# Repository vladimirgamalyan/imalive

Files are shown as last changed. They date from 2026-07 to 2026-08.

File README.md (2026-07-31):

# imalive



An **"I'm alive" heartbeat device** on an ESP32-C3 SuperMini. It helps you tell
whether **mains power is present** at a remote location (home, cottage, office) —
without any voltage sensor.

The trick is inversion: the device is powered by the very mains supply it watches,
so *the device being online is the signal*. It never claims "power is back" (it
cannot tell power from internet or a hang) — it only ever reports that **it is
alive**, and you infer the rest.

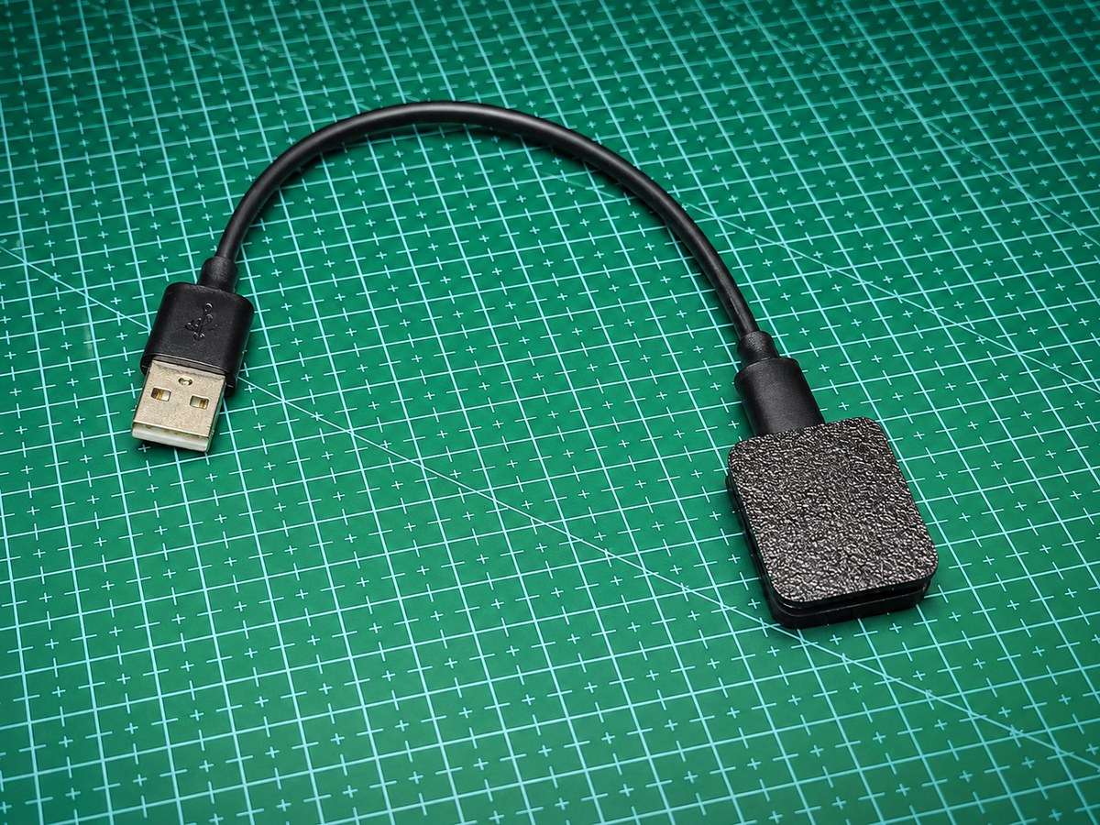
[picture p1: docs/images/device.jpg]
Assembled device


## Highlights

- **No sensors, no cloud, no server** — a $2 board and a Telegram bot. The
  device being online *is* the measurement.
- **One message, zero spam** — the device keeps **editing a single Telegram
  message** instead of posting new ones. Edits are silent; when power drops, the
  message freezes at the last `Last seen`, which is exactly the answer you need.
- **OTA updates over Telegram** — send a `firmware.bin` to the bot and the
  device reflashes itself from anywhere in the world.
- **Round-clock heartbeats** — updates are phase-locked to wall-clock times
  (14:00, 14:30, …), so the timestamps are predictable at a glance.

## How it works

1. On a genuine power-on it connects to WiFi, syncs the clock over NTP, and sends
   a Telegram message with a `Last seen` timestamp (prefixed by `DEVICE_NAME`, if
   set). It ships **muted** (silent); send `/unmute` once so that real power-ons
   notify.
2. While powered, every `HEARTBEAT_MIN` minutes it **edits that same message** to
   refresh a `Last seen` line. Editing raises **no** notification, so the chat is
   not spammed.
3. When power drops, the device dies and the message **freezes** at its last
   `Last seen` — telling you until when power (and the device) was definitely there.

The `message_id` is kept in flash (NVS), so a spontaneous reboot (watchdog / OTA)
resumes the **same** message silently — no false "power is back" ping. Once
`/unmute`d, a real power-on notifies; you can `/mute` again for planned downtime
(see [Commands](#commands)). See [`CONCEPT.md`](CONCEPT.md) and the
[decision records](docs/adr/) for the full rationale.

### Message example

```
The Fine Place Resort
On since: 14:32 24 Jul
Last seen: 16:02 24 Jul (updated every 30m)
```

The `On since` line appears only while notifications are armed (`/unmute`); a muted
device shows just `Last seen`.

## Hardware

- **ESP32-C3 SuperMini** (2.4 GHz WiFi; the C3 has no 5 GHz).
- Powered from USB / a 5 V adapter plugged into the socket you want to monitor.
- Onboard blue LED (GPIO8) is used as a WiFi status indicator:
  - **blinking** — connecting to WiFi;
  - **solid** — connected.
- A 3D-printable enclosure lives in [`case/`](case/) — print `top.stl` and
  `bottom.stl`.

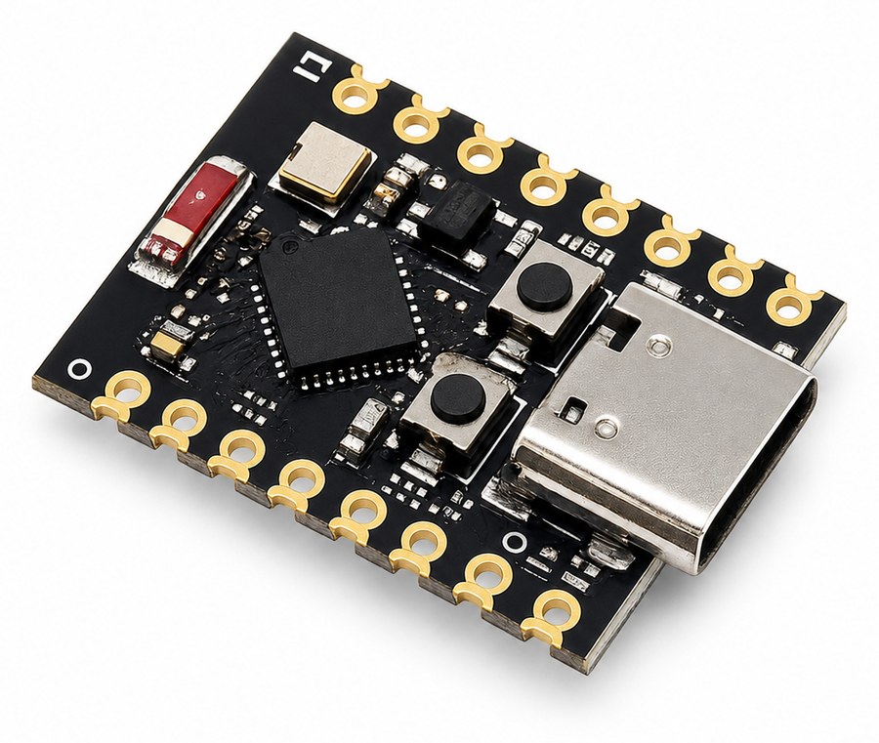
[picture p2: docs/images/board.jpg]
ESP32-C3 SuperMini


## Getting started

### 1. Install PlatformIO

Install [PlatformIO Core](https://docs.platformio.org/en/latest/core/installation/)
(`pio`) or the PlatformIO IDE extension for VS Code.

### 2. Configure

Copy the template and fill in your values:

```sh
cp include/config.example.h include/config.h
```

`include/config.h` is git-ignored and must never be committed.

| Field | Meaning |
| --- | --- |
| `WIFI_SSID` / `WIFI_PASSWORD` | Your 2.4 GHz WiFi credentials |
| `TG_BOT_TOKEN` | Bot token from [@BotFather](https://t.me/BotFather) |
| `TG_CHAT_ID` | **Recipient** chat id — a personal chat or a channel |
| `TG_ADMIN_IDS` | User IDs allowed to command the bot, e.g. `{ 111, 222 }` |
| `HEARTBEAT_MIN` | Heartbeat interval in minutes (default `30`) |
| `DEVICE_NAME` | Optional label shown in the message, e.g. `"Cottage"` |
| `TZ_STRING` | POSIX timezone, DST-aware (default `"ICT-7"`, Asia/Bangkok) |

### 3. Telegram setup

1. Create a bot with [@BotFather](https://t.me/BotFather) and copy its token.
2. **Send your bot a message first** (e.g. `/start`). A bot cannot start a
   conversation, so without this it can never message you.
3. Find your chat id: open
   `https://api.telegram.org/bot<TOKEN>/getUpdates` and read
   `result[].message.chat.id`.
   - ⚠️ This is the **recipient's** id, *not* the bot's own id (the number before
     `:` in the token). Sending to the bot's own id fails.
   - For a **channel**: add the bot as an **administrator** with post permission
     and use a `chat_id` like `-100...` (or `@channelusername`).

Multiple devices can share one chat/channel — each edits only its own message.
Give them distinct `DEVICE_NAME`s to tell them apart.

### 4. Build and flash

```sh
pio run                 # build
pio run -t upload       # build + flash over USB
pio device monitor      # optional serial console (115200 baud)
```

Watch the blue LED: once it stays solid, WiFi is up and the first message should
arrive in your chat within a few seconds.

USB flashing is only needed once — after that the device updates over the air
(see [Firmware update](#firmware-update-ota)).

## Commands

Direct-message the bot (only the user IDs in `TG_ADMIN_IDS` are answered; anyone
else is ignored). The bot publishes these to its Telegram command menu on boot, so
you can pick them from the `/` menu instead of typing:

- `/status` — the device replies with its configuration (name, timezone, chat,
  WiFi SSID, admin IDs) and live state: firmware version, uptime, WiFi signal
  (RSSI), IP address, when it came online, the current time, and whether startup
  pings are muted.
- `/mute` — silence the notification on the next power-on. Send this **before** a
  planned power-off (reflashing, moving sockets); wait for the reply, then power
  down. The device resumes its message silently on the next start.
- `/unmute` — arm startup notifications (the device ships muted), so the next real
  power-on pings again.

On every boot the device also sends a short **silent** notice to each admin's
private chat — so soft reboots (watchdog, panic, OTA), which the main chat
deliberately hides, are still visible to you. It carries the reset reason, the
firmware version, how long the previous session lasted, and the lifetime count
of watchdog reboots (shown once it is non-zero), which tells a one-off network
stall apart from a systematic hang.

## Firmware update (OTA)

There is no update command: build with `pio run`, then send
`.pio/build/esp32-c3-supermini/firmware.bin` to the bot **as a document**. Any
document from an admin whose name ends in `.bin` is treated as firmware — no
command, no caption.

The device flashes it into the spare OTA slot, reboots, silently resumes its
message, and replies with the new version. If the new firmware fails to start
three times in a row, the device rolls back to the previous image and reports
the failure.

## Timezone

`TZ_STRING` is a POSIX TZ string, so daylight-saving transitions are handled
automatically. Examples:

- `ICT-7` — Asia/Bangkok (UTC+7, no DST) — the shipped default.
- `EET-2EEST,M3.5.0/3,M10.5.0/4` — Eastern European (UTC+2 / +3).
- `CET-1CEST,M3.5.0,M10.5.0/3` — Central European (UTC+1 / +2).
- `MSK-3` — Moscow (UTC+3, no DST).

## Limitations

By design the device cannot distinguish **no power** from **no internet** or a
**hang** — all three simply stop the heartbeat. It also does not send an
in-the-moment "power lost" message (no supercapacitor), and a full but very brief
outage (a few seconds) still counts as a real power-on. These are deliberate
tradeoffs; see [`CONCEPT.md` §7](CONCEPT.md) and the [ADRs](docs/adr/).

## Repository layout

```
platformio.ini            PlatformIO project (ESP32-C3 SuperMini, Arduino)
include/config.example.h  config template (copy to config.h)
src/main.cpp              firmware
case/                     3D-printable enclosure (STL)
CONCEPT.md                design concept and tradeoffs
docs/adr/                 architecture decision records
```

## License

[MIT](LICENSE) © Vladimir Gamalyan

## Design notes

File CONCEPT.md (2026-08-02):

# imalive — an "I'm alive" heartbeat device on ESP32-C3

Status: **implemented**. This is the origin concept; where the firmware refined it,
the `docs/adr/` records win — notably ADR-0008 changed the persistence and
notification model described below.

Purpose: help an operator tell whether **mains power is present** at a remote
location — but the device only ever asserts its own **liveness** ("I'm alive").
Inferring "power is present" from that liveness is left to the human. This keeps
the device honest: it never claims something it cannot actually know.

## 1. Idea

An ESP32-C3 device stays permanently plugged into a wall socket at the monitored
location (home / cottage / office). It keeps a connection to Telegram and, as long
as it is running, periodically reports **"I'm alive"** to a chat.

**Core idea (inversion):** the device is powered by the same mains supply it helps
monitor, so its own liveness carries the signal. If the device is alive and online,
the operator can infer that power is present. We do not need a separate voltage
sensor — the device's own power supply *is* what keeps it alive.

The device deliberately reports **only liveness**, never "power is back". It cannot
distinguish "no power" from "no internet" or "device hung" (see §7), so claiming
anything about power directly would be misleading. The project name — *imalive* /
"I'm alive" — matches exactly what the device asserts.

## 2. What the observer sees

- **Device comes online** → it posts a `Last seen` line (prefixed by `DEVICE_NAME`
  if set). A genuine mains power-on posts a **new** message and is the only
  sound-notification — and only when notifications are *armed* (the device ships
  **muted**, ADR-0008). A spontaneous reboot (watchdog / OTA) or a muted restart
  **resumes the existing message** silently.
- **While the device is alive** → every N minutes it **edits that same message**
  (via `editMessageText`), updating the "last seen" line. Editing a Telegram
  message does **not** raise a new notification — so the chat is not spammed.
- **Device stops** (power lost, internet lost, or a hang) → it goes silent and the
  message "freezes" at its last "last seen" value.

So the operator can always look at the last message and reason:
"the device was definitely alive within the last N minutes" (fresh "last seen") or
"the device went silent around HH:MM" (stale "last seen") — and from that infer
whether power is present.

### Message example

Right after coming online (`DEVICE_NAME` is the first line, omitted if unset; the
`On since` line appears only when armed / un-muted; a muted device shows just
`Last seen`):

```
Cottage
On since: 14:32 24 Jul
Last seen: 14:32 24 Jul (updated every 30m)
```

After a few heartbeats (same message, edited in place):

```
Cottage
On since: 14:32 24 Jul
Last seen: 16:02 24 Jul (updated every 30m)
```

If the device goes silent after 16:02, the message stays at "Last seen: 16:02" —
the operator reads that as "the device (and therefore power) was present at least
until ~16:02".

> Note: the runtime wording and language of the Telegram messages is a product
> choice, not fixed here. Russian is the natural default since the operator reads
> them; the examples above are shown in English only to keep this doc consistent.

## 3. Lifecycle (state machine)

```
[POWER ON]
   │
   ▼
Connect to WiFi ──(failed)──► retry with backoff (router may still be booting)
   │ (success)
   ▼
Time sync over NTP
   │
   ▼
Load message_id / online_since / mute from NVS
   │
   ▼
if (reset reason == POWER-ON) and (not muted):
      sendMessage("I'm alive …", notify)    # new session; online_since = now
else:                                        # watchdog / OTA / muted power-off
      editMessageText(message_id, …)         # resume the existing message, silent
   │
   ▼
┌─► wait N minutes
│      │
│      ▼
│  editMessageText(message_id, "… Last seen: HH:MM")
│      │  (edit error — §7 fallback: a fresh silent message)
└──────┘
   ⋮
[DEVICE STOPS] → device goes silent, sends nothing
```

The boot is classified via `esp_reset_reason()` (ADR-0008): only a genuine
`ESP_RST_POWERON` while un-muted starts a fresh, **notifying** session and resets
"online since". Every other cause — watchdog, OTA, software restart — or a muted
power-off **resumes** the persisted message in place, keeping "online since". The
`message_id`, "online since" and mute flag survive in NVS; this is what fixes the
spontaneous-reboot false positive once noted in §7.

## 4. Inferring power loss (from liveness)

The device never sends a "power lost" message — when power drops at that location
the router is usually unpowered too, so the device would not physically have time
to send anything (a supercapacitor / power reserve was deliberately **not** added).
Equally, the device never asserts "power is present"; it only asserts liveness.

Power loss is **inferred by the human** from the "Last seen" line no longer
updating. The **resolution** of that inference equals the heartbeat interval (N
minutes): with N = 30 min the device went silent somewhere in the window
[last "last seen"; last "last seen" + 30 min].

The last heartbeat time is **not** persisted, so the device does not compute a
silent-duration on the next start — only `message_id`, "online since" and the mute
flag are kept (ADR-0008). On a real, un-muted power-on it posts a fresh message and
the previous one freezes, so the human still estimates the gap from that frozen
message in the chat history.

## 5. Timings

- **Online (liveness) detection latency**: practically instant — ESP boot time +
  WiFi connect + NTP ≈ 10–30 s.
- **Heartbeat interval (N)**: default **30 minutes** (candidates: 30 / 60),
  exposed in config. Tradeoff: smaller N → fresher "last seen" and a tighter
  silence estimate, but more Telegram API calls.

## 6. Technical stack and hardware

- **Board**: **ESP32-C3 SuperMini**, 2.4 GHz WiFi. Has an onboard blue LED
  (GPIO8, active LOW) that can be used for status indication.
- **Power**: from USB / a 5V adapter plugged into the monitored socket.
- **Firmware**: C++ on the **Arduino framework** via **PlatformIO**.
- **Telegram link**: HTTPS to `api.telegram.org` (TLS required —
  `WiFiClientSecure`; either a root certificate or `setInsecure()`).
  Two Bot API methods are enough: `sendMessage` and `editMessageText`.
  A full bot library (e.g. UniversalTelegramBot) is optional — for a one-way
  scenario a couple of HTTPS requests plus parsing `message_id` suffice.
- **Time**: NTP (`pool.ntp.org`), DST-aware via a POSIX TZ string from config
  (see "Time source" below).

### Expected project layout (PlatformIO)

```
imalive/
├── platformio.ini
├── include/
│   ├── config.h            # secrets — not committed (.gitignore)
│   └── config.example.h    # template without secrets — committed
├── src/
│   └── main.cpp
└── CONCEPT.md
```

### config.h (draft fields)

```cpp
#define WIFI_SSID        "..."
#define WIFI_PASSWORD    "..."
#define TG_BOT_TOKEN     "123456:ABC..."
#define TG_CHAT_ID       "-1001234567890"   // personal chat (positive id) OR channel (-100…)
#define HEARTBEAT_MIN    30                  // heartbeat interval, minutes
#define TZ_STRING        "ICT-7"                          // Asia/Bangkok (UTC+7, no DST); POSIX TZ — see "Time source"
#define DEVICE_NAME      "Cottage"           // caption in the message (optional)
```

Recipient (`TG_CHAT_ID`) — both variants are supported:

- **Personal chat**: `chat_id` = the user's numeric id (obtained once, e.g. by
  messaging the bot and reading `getUpdates`). The user must start the dialog with
  the bot first.
- **Channel**: `chat_id` of the form `-100…` (or `@username` for a public
  channel). The bot must be **added to the channel as an administrator** with post
  permission.

Timezone and heartbeat interval are fully controlled from `config.h`
(`TZ_STRING`, `HEARTBEAT_MIN`); changing them means editing the config and
rebuilding (no over-the-air provisioning in the current concept).

### Time source

The SuperMini has no battery-backed RTC, so the device knows nothing about the
wall-clock time at boot. Time comes from the network on every start:

1. Connect WiFi.
2. Sync time over SNTP from `pool.ntp.org` (UTC), applying the POSIX `TZ_STRING`
   so local time and DST transitions are handled automatically
   (`configTzTime(TZ_STRING, "pool.ntp.org")` in Arduino).
3. Only **after** a successful sync send the first "I'm alive" — never emit a
   message with unsynced time. If SNTP has not answered yet, retry with backoff.

During a session the internal timer keeps time between syncs (small drift); SNTP
re-syncs periodically to correct it. After a power loss the device reboots and
simply re-syncs — there is no RTC battery, so the wall clock always comes from the
network. (Message state *is* kept in NVS — ADR-0008 — but the clock is not.)

`TZ_STRING` is a POSIX TZ specification, e.g.:

- `ICT-7` — Asia/Bangkok (UTC+7, no DST) — the value shipped in this project.
- `EET-2EEST,M3.5.0/3,M10.5.0/4` — Eastern European (UTC+2, DST → UTC+3).
- `CET-1CEST,M3.5.0,M10.5.0/3` — Central European (UTC+1, DST → UTC+2).
- `MSK-3` — Moscow, fixed UTC+3, no DST.

Dependency note: NTP needs the network, but the device also needs the network to
reach Telegram — so there is no case where it can report but cannot get the time.

### Multiple devices and channels

Several imalive devices can safely share one chat or channel. A device edits only
the message it sent, addressed by the `message_id` returned from its own
`sendMessage` — it never scans the chat or looks at other messages. So multiple
imalive devices (and any unrelated bots posting to the same channel) never contend
for the same message: `message_id` is unique per chat and each device holds its
own. There is nothing to "figure out" at heartbeat time.

Practical notes:

- Give each device a distinct `DEVICE_NAME`. The firmware never relies on it — it
  is purely for the human reader — but it turns a channel into a readable board:
  `Cottage`, `Office`, ...
- A device resumes its own message across reboots (`message_id` in NVS, ADR-0008)
  and posts a new one only on a real, un-muted power cycle; earlier messages freeze
  in place. In a channel this accumulates one frozen message per power cycle per
  device — the intended history.
- If a device's message is deleted or is past its edit window, Telegram rejects the
  next edit and the fallback (ADR-0004) posts a fresh **silent** message to continue
  from. A network failure is not a rejection and never rotates the message
  (ADR-0018).

## 7. Edge cases and limitations (deliberate tradeoffs)

1. **Device liveness ≠ power.** The device asserts only that it is alive. That can
   mean "power present AND internet up AND firmware healthy" all at once — it
   **cannot distinguish** "no power", "no internet/router" and "device hung". All
   three read as "the heartbeat stopped updating". Reporting only liveness (rather
   than "power is back") is the honest framing of exactly this limitation.

2. **Spontaneous reboot (crash / watchdog), not a real outage.** *Resolved
   (ADR-0008).* The boot is classified via `esp_reset_reason()`: a watchdog / OTA /
   software restart is **not** `ESP_RST_POWERON`, so the device resumes its message
   (`message_id` from NVS) silently — no false "power is back". Only a genuine
   power-on notifies.

3. **Router boots slower than the ESP.** After power returns the router may take
   1–2 minutes to come up. WiFi connection must run in a retry loop (backoff)
   rather than failing on the first attempt.

4. **Long session and message-edit limits.** *Verified (ADR-0009):* the Bot API
   lets a bot edit its own message for **48 hours** in a private chat or group, but
   a **channel** post has **no** such limit. So in a private chat the heartbeat's
   edits start failing ~48 h after a message was posted; in a channel the same post
   is edited indefinitely.
   **Fallback:** if `editMessageText` is **rejected** by Telegram (HTTP 400 —
   cannot edit) — send a fresh message **silently** (`disable_notification`) and
   keep editing that one. A transient failure (no connection, 5xx, flood wait) is
   retried and then left for the next heartbeat, so it costs a stale "Last seen"
   rather than an extra message (ADR-0018). Net effect: a private-chat recipient
   accumulates roughly one silent message every ~2 days; a channel recipient does
   not.

5. **Telegram rate limits.** Edits every 30–60 minutes are far within the limits;
   no issues expected.

6. **WiFi drop without power loss.** Auto-reconnect within a session is needed so
   the ability to heartbeat is not lost.

7. **Always-on reliability.** Enable the hardware watchdog (auto-reboot on hang).
   The onboard LED (GPIO8) indicates WiFi status: blinking while connecting,
   solid once connected.

## 8. Out of MVP scope (possible extensions)

- **Further inbound commands** (e.g. `/ping`) beyond the implemented `/status`,
  `/mute` and `/unmute` (ADR-0007, ADR-0008). These poll `getUpdates` and reply;
  the main reporting flow is otherwise one-way (device → chat).
- Storing silence history/durations (NVS currently holds only message state, not a
  log of outages — ADR-0008).
- An in-the-moment "power lost" notification (would require a supercapacitor +
  brownout detection).
- Multiple recipients / a dedicated channel.
- Web-based setup (WiFi provisioning) instead of `config.h`.

## 9. Agreed decisions and open parameters

Decided:

- Board — **ESP32-C3 SuperMini**.
- The device reports **liveness only** ("I'm alive"), never "power is back"; the
  operator infers power presence (ADR-0005).
- **Persistence & notification** — `message_id`, "online since" and a mute flag are
  kept in NVS; the boot is classified via `esp_reset_reason()`, so only a genuine,
  un-muted power-on notifies while soft reboots resume silently. `/mute` / `/unmute`
  toggle it; the device ships muted (ADR-0008).
- Timezone and heartbeat interval — set in **`config.h`** (`TZ_STRING`,
  `HEARTBEAT_MIN`); default interval — **30 minutes**. Timezone uses a DST-aware
  POSIX TZ string (see §6 "Time source").
- Recipient — **personal chat OR channel** (see §6, both supported).
- Onboard LED (GPIO8, active-low) is a **WiFi status indicator**: it blinks while
  connecting and stays solid once connected.

Still open (can be decided during implementation):

- The time-string format in the message (`16:30 24 Jul` — fine or otherwise).

Related ADRs: `docs/adr/` — 0001 (Arduino/PlatformIO), 0002 (heartbeat inference),
0003 (stateless / no NVS — **superseded by 0008**), 0004 (Telegram messaging
model), 0005 (report liveness, not power), 0006 (time source: NTP + POSIX TZ),
0007 (inbound `/status` command), 0008 (NVS persistence, reset-reason classifier,
mute toggle), 0009 (edit window: 48 h chats / unlimited channels), 0010 (preserve
NVS across repartition), 0011 (command admin allowlist).

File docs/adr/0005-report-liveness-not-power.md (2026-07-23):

# 0005. Report device liveness, not power presence, in messages

- Status: Accepted
- Date: 2026-07-24

## Context

The device cannot actually distinguish "mains power present" from "internet up"
or "firmware healthy" — all it truly knows is that it is running and online (see
CONCEPT.md §7 and ADR-0002). Earlier example wording ("power is back") asserted
more than the device can know and could mislead the reader, e.g. during an
internet-only outage or a hang. The project is named *imalive* / "I'm alive",
which already frames the honest primitive.

## Decision

Messages assert **only that the device is alive/online**, never "power is back"
or that power is present. The device sends an "I'm alive" message on start and a
heartbeat that updates a "last seen" line. Inferring mains-power presence from
that liveness is left to the human operator.

## Consequences

- Honest: the device never claims knowledge it lacks; no misleading signal during
  an internet-only outage or a hang.
- The operator interprets liveness as power presence themselves, consistent with
  the limitation in CONCEPT.md §7.
- Product wording is aligned with the project name.
- Refines the message wording used in ADR-0002 and ADR-0004; the detection
  mechanism (0002) and the message lifecycle (0004) are unchanged.

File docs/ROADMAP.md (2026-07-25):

# Roadmap

Planned work. Once a feature is picked up, its design decisions get recorded
as [ADRs](adr/) as usual.

## Captive-portal provisioning (WiFi + Telegram bot)

Let a pre-flashed device be configured without touching the code: on first
boot (or after a config reset) the device raises a SoftAP with a setup portal
where the user picks a WiFi network, enters the password, and pastes a bot
token from [@BotFather](https://t.me/BotFather). The firmware validates both
live and discovers the `chat_id` automatically via a `t.me/<bot>?start=...`
deep link — no manual `getUpdates` spelunking. Credentials move from the
compile-time `include/config.h` into NVS; the `config.h` path stays for
development builds.

Follow-up once this lands: the firmware binary becomes configuration-free, so
a CI-built image works on any device — reinstate the `firmware.bin` asset in
tag releases (superseding ADR-0015), making OTA (ADR-0013) possible straight
from a GitHub release.

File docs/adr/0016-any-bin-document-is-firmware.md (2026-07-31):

# 0016. Any .bin document from an admin is a firmware image

- Status: Accepted (the `/update` usage reply is removed by ADR-0017)
- Date: 2026-07-30

## Context

ADR-0013 §1 gates OTA updates behind a caption: a firmware document is only
flashed when it arrives captioned `/update`. The intent was to make flashing an
explicit operator action rather than an accident.

In practice the gate costs more than it buys:

- Adding a caption is extra manual work on every update, and on mobile it is
  the step most easily forgotten — the document then lands in the chat and is
  silently ignored, which reads as a device failure rather than a missing
  caption.
- The device has exactly one operator, who is on the admin allowlist
  (ADR-0011). Nobody else can reach the OTA path at all.
- The accident the gate guards against — an admin dropping an unrelated `.bin`
  into the bot's private chat — is not a realistic event for this device. That
  chat exists solely to talk to the device.

## Decision

Treat **any document whose file name ends in `.bin`** (case-insensitive) from an
admin as a firmware image. The name is the only gate; captions are ignored, so a
document still captioned `/update` keeps working.

A bare `/update` **text** message continues to reply with usage instructions,
now telling the operator to just send the `.bin`.

This amends ADR-0013 §1 only. Everything else in ADR-0013 stands unchanged:
`getFile` streaming into the free slot, the confirm-or-rollback boot counter,
and the reset-reason model.

## Consequences

- The update cycle is `pio run` → drop the `.bin` into the chat, with nothing to
  remember.
- The `.bin` extension keeps ordinary attachments (photos, documents, logs) from
  entering the OTA path, so a mistaken flash requires sending a file that is
  already named like firmware.
- The protection ADR-0013 attributed to the caption is gone: an admin who sends
  *any* `.bin` now flashes it. The remaining safety net is the one that actually
  covers the dangerous case — a valid-but-wrong image — namely the boot-count
  rollback, which restores the previous slot when the new image fails to
  confirm. A foreign image that boots but lacks the confirmation code is
  therefore rolled back rather than kept.
- `setMyCommands` and the `/update` usage reply change wording; no protocol or
  NVS change, so nothing about ADR-0010 is affected.

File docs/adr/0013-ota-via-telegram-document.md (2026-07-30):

# 0013. OTA updates via a Telegram firmware document, with boot-count rollback

- Status: Accepted (the caption gate in §1 is amended by ADR-0016)
- Date: 2026-07-25

## Context

The device is deployed at a remote location; reflashing over USB requires a
physical visit. Telegram is the device's only channel (ADR-0004, ADR-0007), and
the default partition table already provides two OTA app slots (`app0`/`app1`,
1280 KB each) plus `otadata` — the image currently occupies ~72 % of a slot.

Two forces shape the design:

- **No new infrastructure.** A separate update server or public firmware
  hosting would add a second moving part to an otherwise single-channel device.
- **A bad update must not brick a remote device.** The prebuilt Arduino
  bootloader ships with automatic rollback disabled, so any safety net must
  live at the application level. `Update.end()` verifies image integrity
  (magic byte / checksum), which catches corrupt transfers — but not a build
  that crashes at runtime.

## Decision

1. **Deliver firmware over Telegram itself.** An admin (ADR-0011) sends the
   built `firmware.bin` as a document with caption `/update`. The command
   poller resolves it via `getFile`, streams it from `api.telegram.org` into
   the free OTA slot (`Update.h`), and reboots. Bot API downloads are capped
   at 20 MB — an order of magnitude above the image size. A bare `/update`
   text message replies with usage instructions.

2. **Confirm-or-rollback watchdog** on NVS keys `ota_state`, `ota_boots`,
   `ota_chat`:
   - Before rebooting into the new image, the state is set to *pending* and
     the initiating chat is recorded.
   - Each boot while pending increments `ota_boots` — before networking, so
     even a firmware that never gets online is counted.
   - The first successful update of the tracked message confirms the image:
     the state is cleared and "Update confirmed" is reported to the
     initiating chat.
   - If a boot starts with the counter already exhausted (`> 3`),
     `Update.rollBack()` restores the previous slot and marks the state
     *rolled back*; the previous (OTA-aware) firmware reports the failure
     once online.

3. **Reset-reason model unchanged.** The post-update reboot is a software
   reset, so the ADR-0008 logic resumes the tracked message silently — an
   update never produces a false "power is back" ping. `/status` shows the
   running slot and version for verification.

## Consequences

- Remote updates with zero extra infrastructure; authorization is the existing
  admin allowlist; the whole cycle is `pio run` → drop the `.bin` into the chat.
- Rollback is safe by construction: the spare slot always holds the image that
  was previously running (and confirmed) — a failed update lands back on
  working firmware.
- A hang in the new firmware becomes a WDT reset, which the boot counter also
  catches.
- The watchdog counts *any* reboot while pending — e.g. three consecutive NTP
  failures (ADR-0006 restarts) would roll back a perfectly good image. This is
  accepted: the outcome is a working firmware either way, plus a report.
- The very first rollback target (a pre-OTA firmware) cannot report the
  failure; the operator sees it via the `/status` version instead. From the
  next release on, both slots are OTA-aware.
- TLS to Telegram remains unauthenticated (`setInsecure()`, as elsewhere in
  the firmware): in principle an MITM could substitute a *valid* foreign
  image. Accepted for a personal device — consistent with the existing
  tradeoff noted in the code.
- Any valid ESP32-C3 image is accepted, including one from a different
  project; a wrong-but-bootable image would neither confirm *nor* roll back
  (it lacks the watchdog code). The caption gate makes flashing an explicit
  operator action rather than an accident.
- The firmware must keep fitting a 1280 KB slot; `Update.begin()` enforces
  this and the failure is reported to the chat.
- Relies on ADR-0010 trivially: the partition table is untouched and the new
  NVS keys are additive.

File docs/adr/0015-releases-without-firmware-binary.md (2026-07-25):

# 0015. Tag releases carry no firmware binary

- Status: Accepted
- Date: 2026-07-25

## Context

ADR-0014 attached a CI-built `imalive-<tag>.bin` to every version-tag release.
That binary is built from `config.example.h`, so it cannot work on any real
device: credentials are compile-time constants, and there is no device it
could connect for. Despite the warning in the release notes, a downloadable
`.bin` right next to the OTA instructions invites flashing it onto a remote
device, which would strand the device offline until a USB reflash (the
ADR-0013 rollback does not trigger — the image boots fine). A reference
binary nobody can use turned out to be pure confusion.

## Decision

Keep the tag-triggered release workflow, but publish only the release page
with auto-generated notes — no firmware asset. Firmware continues to be built
locally with the operator's `config.h` and delivered over Telegram OTA
(ADR-0013).

Supersedes ADR-0014.

## Consequences

- Releases remain browsable version milestones with nothing misleading to
  download.
- No canonical binary per version: reproducing an old build means checking out
  the tag and building locally (`build.yml` still proves every push compiles).
- The release job no longer needs Python or PlatformIO and finishes in
  seconds.

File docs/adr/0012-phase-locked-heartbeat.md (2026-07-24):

# 0012. Phase-lock heartbeat edits to round wall-clock times

- Status: Accepted
- Date: 2026-07-24

## Context

The heartbeat was scheduled off a relative `millis()` timer: the first edit fired
`HEARTBEAT_MIN` minutes after boot and every interval thereafter, so its phase was
whatever the power-on moment happened to be. Powering on at 13:11 with a 5-minute
interval produced "Last seen" values of 13:16, 13:21, 13:26 — arbitrary digits.

The operator reads these values by eye to judge freshness and estimate the silence
window; off-grid digits make that arithmetic harder, and several devices sharing a
channel each drift to their own phase, so their timestamps cannot be compared at a
glance. Aligning the edits to round wall-clock times (13:15, 13:20, …) is a
readability win, not a functional one.

## Decision

Add a compile-time flag `HEARTBEAT_ALIGN` (config.h, default on). When it is set
**and** the interval divides an hour evenly (`60 % HEARTBEAT_MIN == 0`, i.e.
5/10/15/20/30/60), each heartbeat is scheduled at the next **local** minute that is
a multiple of `HEARTBEAT_MIN` with seconds zeroed. The target epoch is recomputed
from `getLocalTime` + `mktime` after every edit, not stepped from a fixed origin,
so it tracks NTP re-syncs and never drifts off the displayed minute.

A guard skips any boundary falling within `HEARTBEAT_GUARD_S` (30 s) of the
previous update, so a power-on landing just before a boundary does not fire two
edits seconds apart. 30 s is a wide margin under Telegram's ~1 request/second
per-chat limit (ADR-0004 already keeps heartbeats silent, so this cap is about the
boot collision, not notification spam).

Intervals that do not divide 60, or `HEARTBEAT_ALIGN 0`, keep the original
relative-`millis()` behaviour unchanged. Only the heartbeat scheduler in
`setup()`/`loop()` changed; the notification, mute, edit-fallback and NVS logic are
untouched.

## Consequences

- "Last seen" values land on a tidy grid (13:15, 13:20, …); the inferred silence
  window gets round bounds too. Multiple devices in one channel become visually
  synchronized and directly comparable.
- The **first** interval after boot is shorter than `HEARTBEAT_MIN` by design (a
  13:11 power-on edits at 13:15), and the boot message's own "Last seen" stays
  off-grid until the first aligned edit — accepted.
- Alignment depends on the wall clock, which the design already requires (ADR-0006,
  NTP mandatory before any send). Recomputing per cycle avoids the `millis()`-drift
  case where an edit fires at 13:19:59 and displays the wrong minute.
- Only divisors of 60 are aligned; this is exactly the condition under which the
  grid tiles an hour cleanly. DST transitions can make `mktime` fire one edit an
  hour early/late twice a year — negligible, and moot for the shipped no-DST TZ
  (`ICT-7`).
- Relates to ADR-0004 (single-message heartbeat-edit model) and ADR-0006 (time
  source: NTP + POSIX TZ).

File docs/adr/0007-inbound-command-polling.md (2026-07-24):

# 0007. Optional inbound command polling for /status

- Status: Accepted
- Date: 2026-07-24

> Extended by ADR-0008 (`/mute`, `/unmute`) and ADR-0011 (commands restricted to a
> `TG_ADMIN_IDS` allowlist).

## Context

The device is otherwise a one-way reporter (CONCEPT.md §8). It is useful to query
its state on demand — uptime, WiFi signal, IP, when it came online — without
waiting for the next heartbeat. Telegram delivers inbound messages via `getUpdates`
(polling) or a webhook; a webhook needs a public HTTPS endpoint the device does
not have.

## Decision

Add short-poll `getUpdates` on a timer (default every few seconds), restricted to
message updates, and handle a single command — `/status` — by replying to the
requesting chat with a status summary. Track the update offset in RAM (no NVS) and
drain any pre-boot updates at startup so stale commands are not answered.

## Consequences

- The device is no longer strictly one-way; a user can DM the bot `/status`.
- Cost: continuous polling adds a few TLS requests per minute even when idle —
  acceptable for a mains-powered device.
- The offset is not persisted (consistent with ADR-0003); on reboot pre-boot
  updates are drained once so old commands are ignored.
- Only `/status` is handled; more commands can follow the same pattern.
- Chat ids are handled as 64-bit to support large Telegram ids.

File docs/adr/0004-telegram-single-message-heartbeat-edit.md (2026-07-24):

# 0004. One Telegram message per power-on, updated in place via editMessageText

- Status: Accepted
- Date: 2026-07-24

> Message wording refined by ADR-0005: the "power is back" message is an
> "I'm alive" message. The one-message-per-power-on lifecycle below is unchanged.
>
> Refined by ADR-0008: the `message_id` now persists in NVS, so a soft reboot or
> a muted planned restart resumes the same message instead of posting a new one;
> the power-on notification is conditional (only a genuine, unmuted power-on).
>
> Edit-window risk (below) resolved by ADR-0009: editing is limited to 48 h in a
> chat or group, but unlimited in a channel.

## Context

The device must signal "power is back" and then prove it is still alive over
time, without spamming the chat with repeated notifications. Telegram raises a
notification for a new message (`sendMessage`) but not for an edit
(`editMessageText`). State is not persisted across reboots (see ADR-0003), so a
`message_id` is only valid within a single power session.

## Decision

Per power-on, send exactly **one** new message ("power is back") and keep its
`message_id` in RAM. Emit the heartbeat by **editing that same message**
in place (updating a "last seen" line) every N minutes. Do not send a new
message per heartbeat.

## Consequences

- Only one sound-notification per power-on; heartbeats are silent edits — the
  chat is not spammed.
- The chat history naturally records one message per power-on event; a frozen
  "last seen" marks how long power was present.
- Edit-limit risk: a session lasting days keeps editing an old message, which
  Telegram may refuse to edit (exact limit to be verified during
  implementation). Fallback: on an edit error, send a fresh message and continue
  editing that one; optionally rotate the message on a schedule.
- Both a personal chat and a channel are valid recipients; for a channel the bot
  must be an administrator with post permission.

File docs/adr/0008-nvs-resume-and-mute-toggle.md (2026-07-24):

# 0008. Persist message state in NVS; classify boot by reset reason; mute toggle

- Status: Accepted
- Date: 2026-07-24

> Refined by ADR-0010: how to preserve this NVS state across a partition-table
> change.

## Context

ADR-0003 kept the device stateless: `message_id` lived only in RAM, so *any*
reboot started fresh and sent a new, notifying message. That has two problems:

- **False "power is back" pings.** A watchdog crash or an OTA reboot — where
  power was never cut — produced a new notification (ADR-0003 §7.2), as did a
  planned power-off for reflashing or moving the device to another socket.
- **The tracked message was lost** on every reboot, so it could not be resumed.

We want a notification only on a genuine mains power-on; silence for soft reboots
(watchdog / OTA) and for planned power-offs; and the tracked message to survive
reboots so it is resumed in place.

Two hardware facts constrain the solution: the board has no RTC battery and no
supercapacitor, so **only NVS survives a power loss** (RTC memory does not); and
a Telegram bot cannot read chat history, so `message_id` cannot be recovered from
the chat. Therefore the message state must be persisted to NVS.

## Decision

1. **Persist `{ message_id, online_since_epoch, muted }` in NVS.** Writes happen
   only when a new message is created or the mute flag is toggled — both rare —
   so flash wear is negligible. The heartbeat's `Last seen` is still never
   persisted. This *narrows* ADR-0003 (no frequent NVS writes), not abandons it.

2. **Classify each boot with `esp_reset_reason()`:**
   - `ESP_RST_POWERON` **and** not muted → *announce*: send a new message **with**
     a notification and set `online_since = now`. The previous message stays
     frozen as the outage record.
   - Any other reason (software / watchdog / brownout / …) **or** muted →
     *continuation*: silently **edit** the persisted message and keep the
     persistent `online_since`. If it can no longer be edited (deleted or past
     Telegram's edit window), post a fresh **silent** message.

3. **Add `/mute` and `/unmute` chat commands** — a persistent toggle, **muted by
   default** (the device ships silent; `/unmute` enables power-on pings). `/mute`
   is sent before a planned power-off; its acknowledgement confirms the flag is
   persisted, so it is then safe to cut power. `/unmute` arms. `/status` shows
   `Mute: on/off`. The message still only asserts liveness (ADR-0005 unchanged);
   the notification merely alerts on a real return.

`online_since` is thus continuous across soft reboots and planned restarts and
resets only on a real armed power-on. Uptime since *this* boot is tracked
separately and shown in `/status`.

## Consequences

- No false ping on watchdog / OTA / software reboots (fixes ADR-0003 §7.2) or on
  a planned muted restart. A genuine mains return still pings.
- The tracked message survives reboots and is resumed in place.
- The device **starts muted**, so the first power-on is silent and pings stay off
  until the first `/unmute` — handy for the reboot-heavy setup/testing phase.
- **Footgun:** the mute toggle is persistent — if left muted, the next real
  power-on will not ping. The state is visible in `/status`.
- **Edge — NTP retry:** a real power-on whose first NTP sync fails triggers
  `ESP.restart()` (ADR-0006); its reset reason is software, so that return
  resumes silently instead of pinging. Rare (NTP normally syncs once WiFi is up).
- **Edge — brief full outage:** a full outage of only a few seconds still reports
  `ESP_RST_POWERON` and pings. Short-outage filtering was intentionally not added
  (it would need outage-duration measurement, i.e. frequent NVS writes).
- **USB reflash:** whatever reset reason `esptool` triggers, sending `/mute`
  first guarantees a silent resume; an unmuted bench reflash may ping (harmless at
  the bench).
- Supersedes ADR-0003; refines the messaging model of ADR-0004.

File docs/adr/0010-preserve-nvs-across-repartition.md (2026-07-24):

# 0010. Preserve the NVS partition across partition-table changes

- Status: Accepted
- Date: 2026-07-24

## Context

ADR-0008 stores `message_id`, `online_since`, and the mute flag in NVS. A future
firmware may outgrow the app partition (currently ~70 % of the 1.25 MB app slot in
the default table) and need a new partition layout. Changing the layout must not
silently wipe the saved NVS state.

NVS content is just bytes at a fixed flash offset (`0x9000`, size `0x5000` in the
default layout); the partition table only *maps* names to offsets. The app slot
starts at `0x10000`, above both `nvs` and `otadata`, and grows toward higher
addresses — so enlarging the app does not physically reach `nvs`.

## Decision

When changing the partition table, keep the `nvs` entry **byte-identical** (same
offset and size) and reclaim app space from the OTA / SPIFFS / coredump regions,
which sit at higher offsets. Do **not** run a full `erase_flash` when flashing the
new table.

The standard Arduino "bigger app" schemes (`huge_app.csv`, `min_spiffs.csv`,
`no_ota.csv`) already keep `nvs` at `0x9000 / 0x5000`, so switching to one of them
preserves the stored data.

## Consequences

- NVS data survives a partition-map change as long as the `nvs` entry is unchanged
  and no full erase is performed.
- NVS is lost by a full `erase_flash` / `--erase-all`, or by moving or resizing the
  `nvs` entry. This is **non-fatal by design**: on empty NVS the device creates a
  new *silent* message, resets `online_since`, and reverts to muted (ADR-0008) —
  only message continuity and the mute setting are lost.
- Refines ADR-0008.

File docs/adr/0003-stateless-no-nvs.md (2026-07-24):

# 0003. Operate statelessly — do not persist state to NVS

- Status: Superseded by ADR-0008
- Date: 2026-07-24

> Superseded by ADR-0008: the device now persists a small amount of state
> (`message_id`, `online_since`, mute flag) to NVS. The rare-write reasoning in
> this ADR still holds — the heartbeat `Last seen` is never persisted.

## Context

Across reboots the device could persist data in NVS (non-volatile storage), for
example the current Telegram `message_id` or the last heartbeat time. Persisting
`message_id` would let the device keep editing the same message after a reboot;
persisting the last heartbeat time would let it compute outage duration on the
next start. Both add complexity and flash-wear considerations.

## Decision

Keep the device **stateless across reboots**: store nothing in NVS. `message_id`
lives only in RAM. Every power-on starts fresh: sync time, send a new "power is
back" message, then heartbeat-edit that message during the session.

## Consequences

- Easier: no NVS layout, no flash-wear management, simpler code; a power-on maps
  cleanly to a new chat message, matching the intended real power-cycle behavior.
- Limitation (false positive): a spontaneous reboot (crash / watchdog) is
  indistinguishable from a real power cycle and produces a new "power is back"
  message even though power was never cut. Accepted (see CONCEPT.md §7).
- The device cannot compute outage duration on the next start; the human reads it
  from the previous chat message.
- Constrains related decisions: because `message_id` is not persisted, the
  messaging model is necessarily one new message per power-on (see ADR-0004).

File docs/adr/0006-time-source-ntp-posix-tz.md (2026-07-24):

# 0006. Time source: NTP with a POSIX TZ string (DST-aware)

- Status: Accepted
- Date: 2026-07-24

## Context

The ESP32-C3 SuperMini has no battery-backed RTC, so it holds no wall-clock time
at boot. Messages need local timestamps ("online since", "last seen"). Two
sub-choices: how to obtain the time, and how to represent the timezone — a fixed
numeric offset versus a POSIX TZ string that encodes daylight-saving rules.

## Decision

Obtain time from NTP (SNTP, `pool.ntp.org`) on every boot; keep it with the
internal timer plus periodic re-sync during a session. Represent the timezone as
a POSIX TZ string in config (`TZ_STRING`, applied via `configTzTime`), not a
fixed offset, so DST transitions are handled automatically. Send the first
message only after a successful sync. This project ships with `ICT-7`
(Asia/Bangkok, UTC+7, no DST).

## Consequences

- No RTC battery and no NVS needed; consistent with the stateless model
  (ADR-0003) — each boot simply re-syncs.
- DST is correct without firmware changes in zones that observe it; changing
  location is a one-line config edit.
- Dependency: time requires the network — acceptable, because the device also
  needs the network to reach Telegram, so it can never report yet lack the time.
- Failure handling: if NTP does not sync within a timeout, the device restarts
  rather than sending a wrong timestamp.
- Refines the time note in CONCEPT.md §6 ("Time source").

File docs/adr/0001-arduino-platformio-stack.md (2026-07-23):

# 0001. Use Arduino framework with PlatformIO for firmware

- Status: Accepted
- Date: 2026-07-24

## Context

The device is an always-on ESP32-C3 that must connect to WiFi, sync time over
NTP, and talk to the Telegram Bot API over HTTPS. Three stacks were considered:
ESP-IDF (native C), the Arduino framework (C++), and MicroPython.

Priorities are reliability for continuous operation and low implementation
friction for a small, mostly one-way feature. The functionality needed is
narrow: WiFi, TLS HTTP client, NTP, and two Bot API calls.

## Decision

Write the firmware in C++ on the **Arduino framework**, built with **PlatformIO**.

## Consequences

- Easier: mature, ready-made libraries for WiFi, TLS (`WiFiClientSecure`), NTP,
  and Telegram reduce the code we own; faster to a working device.
- Easier: PlatformIO gives reproducible builds and dependency management.
- Harder / traded away: less low-level control than ESP-IDF (task scheduling,
  power management, fine-grained watchdog control) — acceptable for this scope.
- Rejected MicroPython: convenient to iterate, but considered less robust for an
  unattended always-on device.
- Rejected ESP-IDF: maximum control, but more effort than this narrow feature
  warrants.

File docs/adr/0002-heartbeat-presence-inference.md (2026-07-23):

# 0002. Detect power state by presence inference, not by an active power-loss signal

- Status: Accepted
- Date: 2026-07-24

> Message wording refined by ADR-0005: the device reports liveness ("I'm alive"),
> not "power is back". The detection mechanism below is unchanged.

## Context

The goal is to know whether mains power is present at a location. Because the
device is powered by that same mains supply, its own power state already carries
the signal: online means power is present.

Reporting a power *loss* in the moment is hard: when power drops, the local
router is usually unpowered too, so the device has neither time nor a network
path to send a final "power lost" message. Sending one would require extra
hardware (a supercapacitor / power reserve plus brownout detection).

## Decision

Treat device presence as the power signal. On power-on the device sends a
"power is back" message; while powered it periodically emits a heartbeat. Power
loss is **inferred** from the heartbeat no longer updating. Do **not** add a
supercapacitor/brownout path and do **not** attempt an in-the-moment "power
lost" notification.

## Consequences

- Easier: no extra hardware; the sensor is the power supply itself.
- The time resolution of a detected outage equals the heartbeat interval N
  (the outage lies within [last heartbeat; last heartbeat + N]).
- Limitation: "no power", "no internet/router", and "device hung" are
  indistinguishable — all appear as a stopped heartbeat. Accepted (see
  CONCEPT.md §7).
- "Power lost" is never an explicit event; the observer reads it from a stale
  "last seen" value.
- Reversible later by adding a supercapacitor + brownout ADR if an in-the-moment
  loss notification becomes required.

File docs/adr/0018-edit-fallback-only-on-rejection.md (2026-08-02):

# 0018. Fall back to a fresh message only when Telegram rejects the edit

- Status: Accepted
- Date: 2026-08-02

## Context

ADR-0004 defined the fallback as "on an edit error, send a fresh message and
continue editing that one", and the firmware took that literally: `tgEditMessage`
returned a single `bool`, so a stalled TLS handshake, a read timeout, a 5xx or a
429 flood wait were indistinguishable from Telegram answering "this message
cannot be edited". Any one of them cost a new message.

This was observed in production. The channel recipient
`Electricity - The Fine Place Resort` had been editing the same post for nine
days when, at 09:10 on 2 Aug 2026, the heartbeat posted a fresh one. The
admin chat holds no boot notice for that moment, so there was no reboot; the new
message was created 12 s after the tick, which is the 10 s `TLS_HANDSHAKE_S` cap
plus a reconnect — a network hiccup, not a rejection. The rotation ADR-0009
predicts for private chats had happened in a channel, where no edit window
applies.

The two failures need opposite responses. A rejected edit means the message is
gone or frozen, so retrying it forever would leave the device silent. A transient
failure means the message is intact and reachable a moment later, so replacing it
throws away a working message — and, on a flaky link, does so repeatedly.

## Decision

Classify the outcome of `editMessageText` instead of collapsing it to a bool:

- **HTTP 400** — Telegram parsed the request and refused it (message deleted, past
  the 48 h chat window, ...). *Rejected*: post a fresh **silent** message and
  track that one, exactly as ADR-0004 and ADR-0008 describe.
- **Anything else** — no HTTP status at all, a 5xx, a 429. *Transient*: retry the
  edit up to `EDIT_ATTEMPTS` (3) times, `EDIT_RETRY_MS` (2 s) apart. If every
  attempt fails, keep the tracked `message_id` and skip this update; the next
  heartbeat resumes it.
- `"message is not modified"` still counts as success, unchanged.

The same classification governs the resume path in `setup()`: a boot that cannot
reach Telegram no longer duplicates the message it was trying to resume.

The worst case is 3 × 10 s of handshake plus 2 × 2 s of backoff ≈ 34 s. Every
request feeds the task watchdog on its way out, so the burst cannot trip the 60 s
`WDT_TIMEOUT_S`, and it fits inside even a one-minute heartbeat.

## Consequences

- A network hiccup costs a stale "Last seen" for one interval instead of a
  permanent extra message in the chat. Reading a slightly older timestamp is the
  cheaper failure: §7.1 already says the operator cannot distinguish "no power"
  from "no internet", and one missed edit does not change that judgement.
- A genuinely un-editable message is still replaced, so the 48 h private-chat
  rotation of ADR-0009 works as before — only now it is not triggered early.
- If Telegram itself is unreachable for longer than a heartbeat interval, the
  message simply stops updating, which is indistinguishable from the device being
  down. That is the intended semantics (ADR-0005: liveness, not power).
- 400 is treated as terminal wholesale. A 400 from a cause other than the message
  itself (say a malformed request after a future change) would post a fresh
  message per heartbeat — noisy, but self-evident in the chat and in the serial
  log, which prints the API description on every non-200.
- Refines the fallback of ADR-0004, ADR-0008 §2 and ADR-0009; the messaging model
  is otherwise unchanged.

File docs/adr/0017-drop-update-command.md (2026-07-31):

# 0017. Drop the `/update` command

- Status: Accepted
- Date: 2026-07-31

## Context

ADR-0016 made any `.bin` document from an admin a firmware image, so nothing
about an update is triggered by a command any more. What remained of `/update`
was vestigial: an entry in the `setMyCommands` menu and a text handler that only
replied "just send the `.bin`".

Keeping it costs clarity. A command in the `/` menu reads as a step the operator
must perform, which is exactly the misunderstanding ADR-0016 set out to remove.

## Decision

Remove `/update` entirely — from the `setMyCommands` menu, from the command
handler, and from the README. The bot's menu is `/status`, `/mute`, `/unmute`.

Sending `/update` as text is now ignored like any other unrecognised text.

This amends ADR-0016's "a bare `/update` text message continues to reply with
usage instructions". The OTA mechanism itself (ADR-0013, as amended by
ADR-0016) is unchanged.

## Consequences

- The `/` menu lists only commands that do something.
- An operator used to the old flow gets no hint back when typing `/update`; the
  README documents the document-drop flow under its own section instead.
- Captions were already ignored (ADR-0016), so old habits — sending the `.bin`
  captioned `/update` — keep working unchanged.

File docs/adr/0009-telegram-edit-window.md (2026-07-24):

# 0009. Telegram message-edit window: 48 h in chats, unlimited in channels

- Status: Accepted
- Date: 2026-07-24

## Context

The heartbeat keeps editing one message via `editMessageText` (ADR-0004). How
long an old message stays editable was left open in ADR-0004 and CONCEPT §7.4
("the exact limit **must be verified**").

## Decision

Per Telegram's published limits (confirmable once the device has run past 48 h):

- **Private chat / group:** a bot may edit its own message for **48 hours** after
  it was sent; after that `editMessageText` fails.
- **Channel:** channel posts are **not** subject to the 48 h limit — the bot, as a
  channel administrator, can edit the same post indefinitely.

We accept this instead of working around it. The fallback from ADR-0008 already
covers the chat case: on an edit failure the firmware posts a fresh **silent**
message (`disable_notification`) and continues editing that one.

## Consequences

- **Private-chat recipient:** the tracked message rotates roughly **every ~2
  days** — a new *silent* message (no notification) carrying the same persistent
  `online_since`. The chat slowly accumulates about one message per two days.
- **Channel recipient:** no rotation; a single post is edited forever.
- To avoid accumulation entirely, use a **channel** as the recipient
  (`TG_CHAT_ID` = `-100…`, bot added as administrator). CONCEPT §6 already supports
  both recipient types.
- Resolves the open edit-limit item in ADR-0004 and CONCEPT §7.4.

## Sources

- Telegram — "edit any message within 48 hours": <https://x.com/telegram/status/1168523951695437824>
- Telegram Limits: <https://limits.tginfo.me/en>
- Telegram Bots FAQ: <https://core.telegram.org/bots/faq>

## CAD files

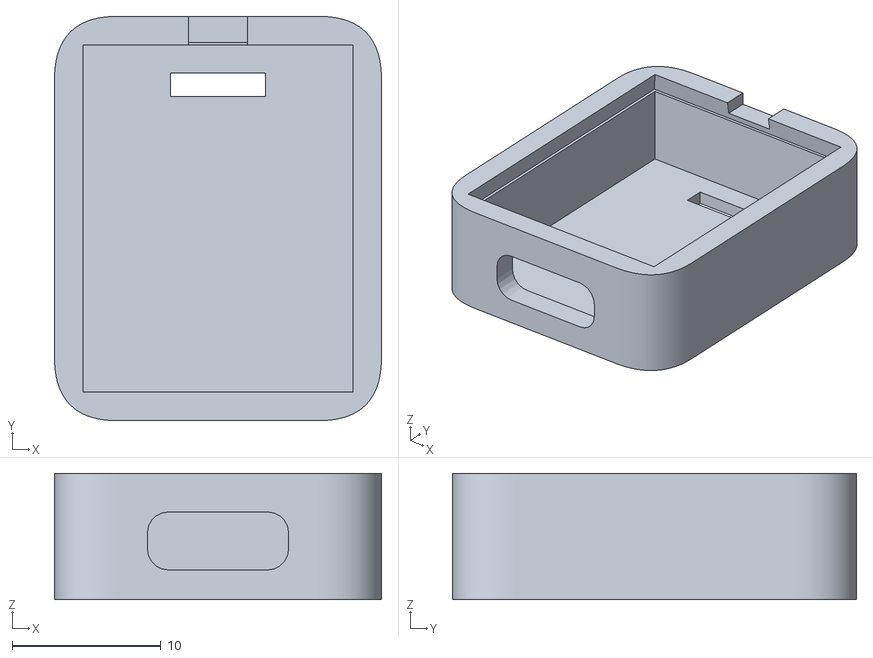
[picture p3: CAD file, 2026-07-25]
case/bottom.stl
22.0 x 27.2 x 8.50

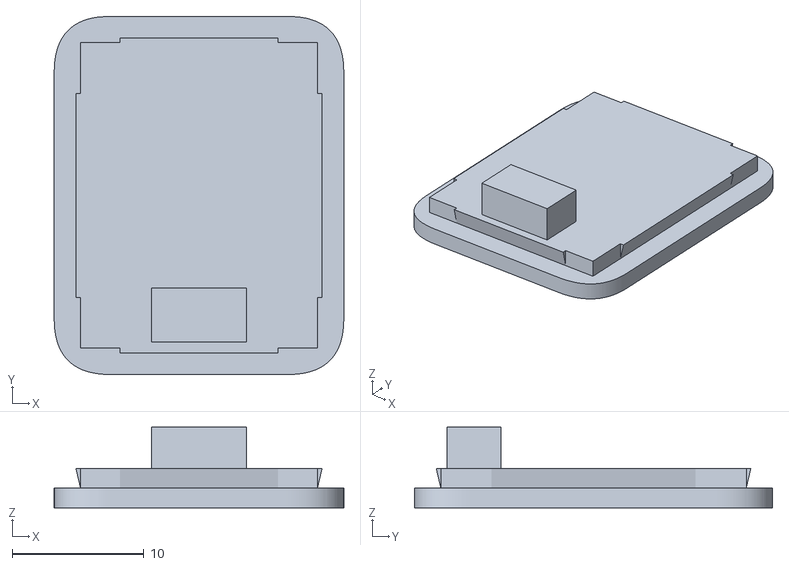
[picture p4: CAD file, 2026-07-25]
case/top.stl
22.0 x 27.2 x 6.13

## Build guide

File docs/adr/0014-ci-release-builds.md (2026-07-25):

# 0014. CI release builds from version tags

- Status: Superseded by ADR-0015
- Date: 2026-07-25

## Context

Firmware is normally built locally: credentials live in the git-ignored
`include/config.h` and are baked in at compile time. CI (`build.yml`) already
proves every push compiles by substituting `config.example.h`, but no binary is
tied to a version number — OTA (ADR-0013) flashes whatever the operator last
built, and old versions are not reconstructible without checking out and
rebuilding the exact commit.

## Decision

A `release` workflow triggers on `v*` tags, builds exactly like CI (template
config), and publishes `imalive-<tag>.bin` as a GitHub release asset with
auto-generated notes plus a fixed warning about the placeholder credentials.

## Consequences

- Every version tag yields a canonical reference binary and a release-notes
  page for free; the version history becomes browsable outside git.
- The asset is a **reference artifact, not an OTA payload**: it carries
  `config.example.h` placeholders, so flashed onto a configured device it
  would boot but never reach WiFi, leaving the device unreachable until a USB
  reflash. The ADR-0013 boot-count rollback would NOT catch this - it counts
  only boots that fail, and this image boots successfully. Devices must keep
  receiving locally built binaries; the release notes state this.
- Nothing enforces that `FW_VERSION` in `src/main.cpp` matches the tag; keeping
  them in sync stays an operator responsibility.

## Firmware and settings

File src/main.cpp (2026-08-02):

// imalive — an "I'm alive" heartbeat device on ESP32-C3 SuperMini.
//
// On a genuine power-on the device connects to WiFi, syncs time over NTP, and
// sends an "I'm alive" message to a Telegram chat with a notification. While it
// stays powered it edits that same message every HEARTBEAT_MIN minutes (a silent
// heartbeat). The message_id is kept in NVS, so a soft reboot (watchdog / OTA)
// or a planned muted restart silently resumes the same message instead of
// pinging again. When power is lost the device dies and the message freezes at
// its last "Last seen" value. See CONCEPT.md and docs/adr/ for the rationale.
//
// Firmware updates over the air: an admin sends the new .bin as a Telegram
// document; a boot-count watchdog rolls back to the previous image if the new
// one fails to confirm (ADR-0013, ADR-0016).

#include <Arduino.h>
#include <WiFi.h>
#include <WiFiClientSecure.h>
#include <HTTPClient.h>
#include <Update.h>
#include <ArduinoJson.h>
#include <time.h>
#include <Preferences.h>
#include "esp_task_wdt.h"
#include "esp_system.h"
#include "esp_ota_ops.h"

#include "config.h"

// Default the alignment flag on if a pre-existing config.h predates it.
#ifndef HEARTBEAT_ALIGN
#define HEARTBEAT_ALIGN 1
#endif

// Fixed tunables (not exposed in config.h).
static const char* NTP_SERVER = "pool.ntp.org";
static const uint32_t WIFI_BLINK_MS = 250;      // status-LED blink period while connecting
static const uint32_t NTP_TIMEOUT_MS = 30000;
static const uint32_t WDT_TIMEOUT_S = 60;
static const uint32_t HEARTBEAT_MS = (uint32_t)HEARTBEAT_MIN * 60UL * 1000UL;
static const uint32_t CMD_POLL_MS = 4000;       // /status command poll interval
// Cap on the TLS handshake. The Arduino core defaults to 120 s, twice the
// watchdog period, so a stalled handshake (link up but no packets getting
// through) reboots the device instead of failing the request.
static const uint32_t TLS_HANDSHAKE_S = 10;
// Retries for a heartbeat edit that failed for a transient reason (ADR-0018).
// Worst case 3 * TLS_HANDSHAKE_S + 2 * EDIT_RETRY_MS ~= 34 s, so the burst fits
// inside a one-minute heartbeat and every request feeds the watchdog itself.
static const int EDIT_ATTEMPTS = 3;
static const uint32_t EDIT_RETRY_MS = 2000;

// Heartbeat edits are phase-locked to wall-clock multiples of HEARTBEAT_MIN when
// HEARTBEAT_ALIGN is on and the interval divides an hour evenly (so 5/10/15/30/60
// tile the hour cleanly: "Last seen" lands on :00, :05, :10, ...). A boundary
// falling within HEARTBEAT_GUARD_S of the previous update is skipped to the next
// one, so a power-on never fires two edits seconds apart. 30 s is a wide margin
// under Telegram's ~1 request/second-per-chat limit.
static const bool HEARTBEAT_ALIGNED = (HEARTBEAT_ALIGN != 0) && (60 % HEARTBEAT_MIN == 0);
static const int  HEARTBEAT_GUARD_S = 30;

static const char* FW_VERSION  = "0.2.4";
static const char* BUILD_STAMP = __DATE__ " " __TIME__;  // set at compile time

// Telegram user IDs allowed to issue commands (config.h); others are ignored.
static const long long g_adminIds[] = TG_ADMIN_IDS;
static const size_t g_adminCount = sizeof(g_adminIds) / sizeof(g_adminIds[0]);

// Runtime state. The tracked message_id, the session's "online since", and the
// startup-ping mute flag survive reboots in NVS (see the Persistent state
// section); everything else is RAM only.
static long g_messageId = -1;   // Telegram message id of the tracked message (NVS)
static String g_onlineSince;    // local-time string of the session start
static time_t g_onlineSinceEpoch = 0;  // session start epoch, persistent across reboots (NVS)
static time_t g_bootEpoch = 0;  // epoch of this boot, for uptime-since-boot
static bool g_muted = true;     // if set, a power-on resumes silently — no ping (NVS); muted by default
static uint32_t g_lastHeartbeatMs = 0;
static time_t g_nextHeartbeatEpoch = 0;  // next aligned heartbeat, wall-clock (RAM; aligned mode only)
static long g_updateOffset = 0; // getUpdates acknowledge cursor (RAM only)
static uint32_t g_lastPollMs = 0;

// OTA confirmation state (ADR-0013). A flashed update must confirm itself
// within OTA_MAX_BOOTS boots or the previous image is restored.
enum : uint8_t { OTA_IDLE = 0, OTA_PENDING = 1, OTA_ROLLED_BACK = 2 };
static uint8_t g_otaState = OTA_IDLE;   // NVS
static long long g_otaChat = 0;         // chat that initiated the update (NVS)

// Boot diagnostics (NVS). Each boot stores its own epoch, so the next one can
// report how long this session lasted, and a watchdog reset bumps a lifetime
// counter. Both are reported in the admin boot notice: a single unlucky network
// stall looks the same as a systematic hang without them.
static time_t g_prevBootEpoch = 0;   // epoch of the previous boot (NVS)
static uint32_t g_wdtReboots = 0;    // lifetime count of watchdog reboots (NVS)

// ---------------------------------------------------------------------------
// Status LED
// Onboard blue LED on the ESP32-C3 SuperMini: GPIO8, active-low (LOW = lit).
// Blinks while connecting to WiFi, solid on once connected.
// ---------------------------------------------------------------------------

static const int  LED_PIN = 8;
static const bool LED_ACTIVE_LOW = true;

static void ledSet(bool on) {
  bool level = LED_ACTIVE_LOW ? !on : on;
  digitalWrite(LED_PIN, level ? HIGH : LOW);
}

static void ledToggle() {
  static bool state = false;
  state = !state;
  ledSet(state);
}

// ---------------------------------------------------------------------------
// Time
// ---------------------------------------------------------------------------

static String formatLocalTime() {
  struct tm timeinfo;
  if (!getLocalTime(&timeinfo)) {
    return String("--:-- -- ---");
  }
  char buf[16];
  strftime(buf, sizeof(buf), "%H:%M %d %b", &timeinfo);
  return String(buf);
}

// Format an arbitrary epoch as local "dd.mm HH:MM" (for a stored session start).
static String formatLocalTimeAt(time_t t) {
  struct tm timeinfo;
  localtime_r(&t, &timeinfo);
  char buf[16];
  strftime(buf, sizeof(buf), "%H:%M %d %b", &timeinfo);
  return String(buf);
}

// Human-readable "Xd Xh Xm" from a whole-second span. uint32_t seconds spans
// ~136 years, so this never wraps in practice.
static String formatDuration(uint32_t seconds) {
  uint32_t d = seconds / 86400; seconds %= 86400;
  uint32_t h = seconds / 3600;  seconds %= 3600;
  uint32_t m = seconds / 60;
  char buf[32];
  snprintf(buf, sizeof(buf), "%lud %luh %lum",
           (unsigned long)d, (unsigned long)h, (unsigned long)m);
  return String(buf);
}

// Human-readable span from an epoch timestamp up to now. Uses wall-clock time,
// so it does not suffer the ~49-day millis() wrap.
static String formatDurationSince(time_t start) {
  time_t now = time(nullptr);
  uint32_t seconds = (now > start) ? (uint32_t)(now - start) : 0;
  return formatDuration(seconds);
}

// Epoch of the next wall-clock-aligned heartbeat: the next local minute that is a
// multiple of HEARTBEAT_MIN with seconds zeroed, pushed forward until it is at
// least HEARTBEAT_GUARD_S after `notBefore` (the previous update). Returns 0 if
// the clock is not set. Only meaningful when HEARTBEAT_ALIGNED.
static time_t nextAlignedHeartbeat(time_t notBefore) {
  struct tm timeinfo;
  if (!getLocalTime(&timeinfo)) {
    return 0;
  }
  timeinfo.tm_sec = 0;
  // Snap up to the next multiple-of-interval minute; mktime normalizes a value
  // >= 60 into the following hour.
  timeinfo.tm_min = (timeinfo.tm_min / HEARTBEAT_MIN + 1) * HEARTBEAT_MIN;
  time_t next = mktime(&timeinfo);
  while ((long)(next - notBefore) < HEARTBEAT_GUARD_S) {
    next += (time_t)HEARTBEAT_MIN * 60;
  }
  return next;
}

// Start SNTP and block until the clock is set or NTP_TIMEOUT_MS elapses.
static bool syncTime() {
  configTzTime(TZ_STRING, NTP_SERVER);
  struct tm timeinfo;
  uint32_t start = millis();
  while (!getLocalTime(&timeinfo, 1000)) {
    if (millis() - start > NTP_TIMEOUT_MS) {
      return false;
    }
    Serial.println("Waiting for NTP time sync...");
    esp_task_wdt_reset();
  }
  return true;
}

// ---------------------------------------------------------------------------
// WiFi
// ---------------------------------------------------------------------------

// Block until connected. The router may still be booting after power returns,
// so we keep retrying (CONCEPT.md §7).
static void connectWiFi() {
  if (WiFi.status() == WL_CONNECTED) {
    ledSet(true);  // solid on = connected
    return;
  }
  Serial.printf("Connecting to WiFi '%s'...\n", WIFI_SSID);
  WiFi.mode(WIFI_STA);
  WiFi.begin(WIFI_SSID, WIFI_PASSWORD);

  int ticks = 0;
  while (WiFi.status() != WL_CONNECTED) {
    ledToggle();            // blink while connecting
    delay(WIFI_BLINK_MS);
    esp_task_wdt_reset();
    // Re-issue begin() roughly every 20 s in case the router is still booting.
    if (++ticks % (20000 / WIFI_BLINK_MS) == 0) {
      Serial.println("Still no WiFi, re-issuing begin()...");
      WiFi.disconnect();
      WiFi.begin(WIFI_SSID, WIFI_PASSWORD);
    }
  }
  ledSet(true);  // solid on = connected
  Serial.printf("WiFi connected, IP %s\n", WiFi.localIP().toString().c_str());
}

// ---------------------------------------------------------------------------
// Persistent state (NVS)
// A power loss wipes RAM, so the tracked message_id, the session's "online
// since", and the mute flag live in NVS. Writes happen only when a new message
// is created, the mute flag is toggled, or a boot records its diagnostics — all
// rare, so flash wear is negligible. This narrows ADR-0003 (see ADR-0008).
// ---------------------------------------------------------------------------

static Preferences g_prefs;

// Open NVS and load the persisted state into the globals.
static void stateBegin() {
  g_prefs.begin("imalive", false);
  g_messageId = g_prefs.getLong("msg_id", -1);
  g_onlineSinceEpoch = (time_t)g_prefs.getLong64("since", 0);
  g_muted = g_prefs.getBool("muted", true);  // muted by default: silent until /unmute
  g_otaState = g_prefs.getUChar("ota_state", OTA_IDLE);
  g_otaChat = (long long)g_prefs.getLong64("ota_chat", 0);
  g_prevBootEpoch = (time_t)g_prefs.getLong64("boot_ep", 0);
  g_wdtReboots = g_prefs.getULong("wdt_n", 0);
}

// Persist the tracked message and its session start (after creating a message).
static void saveSession() {
  g_prefs.putLong("msg_id", (int32_t)g_messageId);
  g_prefs.putLong64("since", (int64_t)g_onlineSinceEpoch);
}

static void saveMuted() {
  g_prefs.putBool("muted", g_muted);
}

static void saveOtaState() {
  g_prefs.putUChar("ota_state", g_otaState);
  g_prefs.putLong64("ota_chat", (int64_t)g_otaChat);
}

// Persist this boot's diagnostics: its epoch (read back by the next boot as the
// start of this session) and the watchdog counter. Call once the clock is set,
// so the stored epoch is real wall-clock time.
static void saveBootStats(esp_reset_reason_t reason) {
  if (reason == ESP_RST_TASK_WDT || reason == ESP_RST_INT_WDT || reason == ESP_RST_WDT) {
    g_wdtReboots++;
    g_prefs.putULong("wdt_n", g_wdtReboots);
  }
  g_prefs.putLong64("boot_ep", (int64_t)g_bootEpoch);
}

// ---------------------------------------------------------------------------
// Telegram Bot API
// ---------------------------------------------------------------------------

// Posts to the Bot API. When httpCode is given it receives the HTTP status, or 0
// if the request never got an answer — that is what tells a rejection by Telegram
// apart from a network failure (ADR-0018).
static bool tgApiPost(const char* method, const String& body, String& response,
                      int* httpCode = nullptr) {
  if (httpCode) {
    *httpCode = 0;
  }
  WiFiClientSecure client;
  // No server certificate validation. Simple and memory-light; acceptable for a
  // personal device. Pin Telegram's root CA here for a hardened setup.
  client.setInsecure();
  client.setHandshakeTimeout(TLS_HANDSHAKE_S);

  HTTPClient https;
  https.setTimeout(15000);  // response read only; the handshake has its own cap
  String url = String("https://api.telegram.org/bot") + TG_BOT_TOKEN + "/" + method;
  if (!https.begin(client, url)) {
    Serial.println("HTTPS begin() failed");
    return false;
  }
  https.addHeader("Content-Type", "application/json");

  int code = https.POST(body);
  if (httpCode) {
    *httpCode = code;
  }
  bool ok = false;
  if (code > 0) {
    response = https.getString();
    ok = (code == HTTP_CODE_OK);
    if (!ok) {
      Serial.printf("Telegram %s HTTP %d: %s\n", method, code, response.c_str());
    }
  } else {
    Serial.printf("Telegram %s failed: %s\n", method, https.errorToString(code).c_str());
  }
  https.end();
  // Every path above is time-bounded (handshake and read timeouts), so a request
  // that returns here means the loop is making progress. Feed the watchdog so a
  // burst of consecutive requests — a heartbeat edit falling back to a fresh
  // send, or the several sends in setup() — cannot add up past WDT_TIMEOUT_S.
  esp_task_wdt_reset();
  return ok;
}

// Post a prepared sendMessage document; returns the new message_id, or -1.
static long tgSendPrepared(JsonDocument& doc) {
  String body;
  serializeJson(doc, body);

  String response;
  if (!tgApiPost("sendMessage", body, response)) {
    return -1;
  }

  JsonDocument res;
  DeserializationError err = deserializeJson(res, response);
  if (err || !res["ok"].as<bool>()) {
    Serial.println("sendMessage: unexpected response");
    return -1;
  }
  return res["result"]["message_id"].as<long>();
}

// Send a new message to the configured recipient; returns its message_id, or -1.
// When silent, Telegram delivers it without a notification (disable_notification).
static long tgSendMessage(const String& text, bool silent) {
  JsonDocument doc;
  doc["chat_id"] = TG_CHAT_ID;
  doc["text"] = text;
  if (silent) {
    doc["disable_notification"] = true;
  }
  return tgSendPrepared(doc);
}

// Reply to a specific chat (used by command handling). Chat ids are 64-bit.
static void tgReply(long long chatId, const String& text, bool silent = false) {
  JsonDocument doc;
  doc["chat_id"] = chatId;
  doc["text"] = text;
  if (silent) {
    doc["disable_notification"] = true;
  }
  tgSendPrepared(doc);
}

// Why an edit did not go through. Only EDIT_REJECTED — Telegram answered "400
// Bad Request", so the message is deleted or past its edit window — justifies
// posting a fresh one; EDIT_TRANSIENT means the message is still fine and the
// request never reached Telegram (ADR-0018).
enum EditResult { EDIT_OK, EDIT_TRANSIENT, EDIT_REJECTED };

// Edit an existing message in place.
static EditResult tgEditMessage(long messageId, const String& text) {
  JsonDocument doc;
  doc["chat_id"] = TG_CHAT_ID;
  doc["message_id"] = messageId;
  doc["text"] = text;
  String body;
  serializeJson(doc, body);

  String response;
  int httpCode = 0;
  if (tgApiPost("editMessageText", body, response, &httpCode)) {
    return EDIT_OK;
  }
  // Telegram rejects an edit whose text equals the current message content with
  // "message is not modified". That means the message already shows what we want,
  // so treat it as success rather than posting a fresh message.
  if (response.indexOf("message is not modified") >= 0) {
    return EDIT_OK;
  }
  return (httpCode == HTTP_CODE_BAD_REQUEST) ? EDIT_REJECTED : EDIT_TRANSIENT;
}

// Edit the tracked message, retrying a transient failure a few times. Returns
// EDIT_TRANSIENT only when every attempt failed that way, so the caller can skip
// this update instead of spending a fresh message on a network hiccup.
static EditResult tgEditWithRetry(long messageId, const String& text) {
  EditResult result = EDIT_TRANSIENT;
  for (int i = 0; i < EDIT_ATTEMPTS && result == EDIT_TRANSIENT; i++) {
    if (i > 0) {
      delay(EDIT_RETRY_MS);
      esp_task_wdt_reset();
    }
    result = tgEditMessage(messageId, text);
  }
  return result;
}

// Register the bot's command menu (setMyCommands) so the commands are discoverable
// in the Telegram UI. Idempotent; called once per boot.
static void tgSetCommands() {
  JsonDocument doc;
  JsonArray cmds = doc["commands"].to<JsonArray>();
  JsonObject s = cmds.add<JsonObject>();
  s["command"] = "status";
  s["description"] = "Show device status";
  JsonObject m = cmds.add<JsonObject>();
  m["command"] = "mute";
  m["description"] = "Mute startup notification";
  JsonObject u = cmds.add<JsonObject>();
  u["command"] = "unmute";
  u["description"] = "Re-arm startup notification";
  String body;
  serializeJson(doc, body);
  String response;
  tgApiPost("setMyCommands", body, response);
}

// ---------------------------------------------------------------------------
// OTA update (ADR-0013)
// An admin sends the firmware .bin as a document (any name ending in .bin); it
// is fetched via getFile and streamed into the free OTA slot. The new firmware
// must confirm itself (first successful update of the tracked message) within
// OTA_MAX_BOOTS boots, or otaCheckOnBoot() restores the previous image.
// ---------------------------------------------------------------------------

static const uint8_t OTA_MAX_BOOTS = 3;

// Resolve a Telegram file_id to its download path on api.telegram.org.
static String tgGetFilePath(const char* fileId) {
  JsonDocument doc;
  doc["file_id"] = fileId;
  String body;
  serializeJson(doc, body);

  String response;
  if (!tgApiPost("getFile", body, response)) {
    return String();
  }
  JsonDocument res;
  if (deserializeJson(res, response) || !res["ok"].as<bool>()) {
    return String();
  }
  return res["result"]["file_path"].as<String>();
}

// Download the firmware image and stream it into the free OTA slot. Returns an
// empty string on success, or a short error description.
static String otaDownloadAndFlash(const String& filePath) {
  WiFiClientSecure client;
  client.setInsecure();  // same tradeoff as tgApiPost
  client.setHandshakeTimeout(TLS_HANDSHAKE_S);

  HTTPClient https;
  https.setTimeout(15000);
  String url = String("https://api.telegram.org/file/bot") + TG_BOT_TOKEN + "/" + filePath;
  if (!https.begin(client, url)) {
    return String("HTTPS begin() failed");
  }
  int code = https.GET();
  if (code != HTTP_CODE_OK) {
    https.end();
    return "download HTTP " + String(code);
  }
  int total = https.getSize();
  if (total <= 0) {
    https.end();
    return String("missing Content-Length");
  }
  if (!Update.begin(total)) {
    https.end();
    return "Update.begin: " + String(Update.errorString());
  }

  WiFiClient* stream = https.getStreamPtr();
  // Static, not stack: this function is inlined into the command poller, and a
  // 4 KB stack buffer overflows the 8 KB loopTask stack on every poll once the
  // TLS machinery is entered. Single-task use (loopTask only), so this is safe.
  static uint8_t buf[4096];
  int written = 0;
  uint32_t lastData = millis();
  while (written < total) {
    esp_task_wdt_reset();  // the download may outlast the watchdog period
    size_t avail = stream->available();
    if (avail == 0) {
      if (!client.connected() || millis() - lastData > 20000) {
        break;  // connection lost or stalled
      }
      delay(10);
      continue;
    }
    size_t n = stream->readBytes(buf, avail < sizeof(buf) ? avail : sizeof(buf));
    if (n == 0 || Update.write(buf, n) != n) {
      break;
    }
    written += n;
    lastData = millis();
  }
  https.end();

  if (written < total || !Update.end()) {
    String err = "flash failed at " + String(written) + "/" + String(total)
               + " (" + Update.errorString() + ")";
    Update.abort();
    return err;
  }
  return String();
}

// True if a document name looks like a firmware image, i.e. ends in ".bin"
// (case-insensitive). This is the whole gate for an OTA update: any such
// document from an admin is flashed, no caption needed (ADR-0016).
static bool isFirmwareName(const char* name) {
  size_t n = strlen(name);
  return n > 4 && strcasecmp(name + n - 4, ".bin") == 0;
}
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
void loop() {
  esp_task_wdt_reset();

  if (WiFi.status() != WL_CONNECTED) {
    Serial.println("WiFi lost; reconnecting...");
    connectWiFi();
  }

  if (millis() - g_lastPollMs >= CMD_POLL_MS) {
    g_lastPollMs = millis();
    pollCommands();
  }

  bool heartbeatDue = HEARTBEAT_ALIGNED
      ? (g_nextHeartbeatEpoch > 0 && time(nullptr) >= g_nextHeartbeatEpoch)
      : (millis() - g_lastHeartbeatMs >= HEARTBEAT_MS);
  if (heartbeatDue) {
    g_lastHeartbeatMs = millis();

    String lastSeen = formatLocalTime();
    String text = buildMessage(lastSeen);

    // Having no tracked message at all (the initial send failed) counts as a
    // rejection: there is nothing to edit, so a fresh message is due.
    EditResult edit = (g_messageId > 0) ? tgEditWithRetry(g_messageId, text) : EDIT_REJECTED;
    bool ok = (edit == EDIT_OK);
    if (edit == EDIT_REJECTED) {
      // Fallback (ADR-0004): message too old to edit, or never sent — send a
      // fresh one silently (no restart happened) and keep editing that one.
      Serial.println("Edit rejected; sending a fresh (silent) message.");
      long newId = tgSendMessage(text, true);
      if (newId > 0) {
        g_messageId = newId;
        saveSession();
        ok = true;
      }
    } else if (!ok) {
      // Transient (ADR-0018): the message is intact, so keep it and try again at
      // the next heartbeat rather than spending a new message on a hiccup.
      Serial.println("Edit failed; keeping the message and retrying next heartbeat.");
    }
    if (ok) {
      otaReportOnline();  // resolve a pending update now that Telegram works
    }
    if (HEARTBEAT_ALIGNED) {
      g_nextHeartbeatEpoch = nextAlignedHeartbeat(time(nullptr));
    }
    Serial.printf("Heartbeat: last seen %s (message id %ld)\n", lastSeen.c_str(), g_messageId);
  }

  delay(1000);
}

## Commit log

2026-07-23 Initial commit: imalive concept and decision records
    Add the concept for imalive, an ESP32-C3 "I'm alive" heartbeat device
    used to infer whether mains power is present at a remote location.
    - CONCEPT.md: concept, lifecycle, Telegram message model, and tradeoffs
    - docs/adr/0001-0005: accepted architecture decision records
    - CLAUDE.md / AGENTS.md / CODE_GUIDELINES.md: AI workflow templates
    - .gitignore: keep secrets (config.h) and build output out of git
    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
2026-07-23 Add DST-aware time source docs and .gitattributes
    - CONCEPT.md: add "Time source" subsection (no RTC, NTP on each boot,
    startup order WiFi -> NTP -> send, with retry) and switch config from
    TZ_OFFSET_SEC to a POSIX TZ_STRING that handles DST automatically
    - .gitattributes: normalize text to LF, keep Windows scripts CRLF,
    mark binary assets
    Claude-Session: https://claude.ai/code/session_01W7hXaCjRjW4hKzFebVSm6J
2026-07-24 Implement firmware: WiFi + NTP + Telegram heartbeat
    - src/main.cpp: connect WiFi (retry while router boots), NTP sync with a
    DST-aware POSIX TZ, send one "I'm alive" message per power-on, then silent
    heartbeat edits every HEARTBEAT_MIN; fall back to a fresh message if an edit
    fails; task watchdog for always-on reliability
    - platformio.ini: ESP32-C3 SuperMini env (Arduino + ArduinoJson), USB CDC serial
    - include/config.example.h: config template; timezone Asia/Bangkok (ICT-7)
    - docs/adr/0006: time source (NTP + POSIX TZ string)
    - CONCEPT.md: align the TZ example with the shipped Asia/Bangkok default
    Builds clean with `pio run` (flash 69%, RAM 12%).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
    [main.cpp]
2026-07-24 Add onboard LED as WiFi status indicator
    - src/main.cpp: GPIO8 (active-low) blinks while connecting to WiFi and stays
    solid once connected — a headless status cue, handy since USB serial is not
    reliably readable on the C3
    - CONCEPT.md: record the LED decision (§7, §9)
    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
2026-07-24 Document multi-device / channel behaviour in CONCEPT.md
    Each device edits only its own message_id, so multiple imalive devices (or
    other bots) can share one channel without contention. Note the DEVICE_NAME,
    frozen-history, and delete/fallback implications.
    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
2026-07-24 Add README with quick-start and Telegram setup
    Practical getting-started guide: hardware, config.h fields, bot token / chat_id
    setup (including the must-message-bot-first and chat-id-is-not-bot-id gotchas),
    build/flash, LED status, timezone, and limitations. Design details link to
    CONCEPT.md and the ADRs.
    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
2026-07-24 Add GitHub Actions CI and /status command
    CI:
    - .github/workflows/build.yml: build the firmware (pio run) on push and PR;
    seeds config.h from config.example.h so the build has a config
    - README: build-status badge
    /status command (ADR-0007):
    - src/main.cpp: short-poll getUpdates on a timer and reply to /status with
    uptime, WiFi RSSI, IP, online-since and current time; drain pre-boot updates
    so stale commands are ignored; handle chat ids as 64-bit
    - docs/adr/0007: record the inbound-command-polling decision
    - README / CONCEPT.md: document the /status command
    Claude-Session: https://claude.ai/code/session_01W7hXaCjRjW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
    [main.cpp]
2026-07-24 Show elapsed time on "Online since" and fix 49-day uptime overflow
    Append "(Xd Xh Xm ago)" to the "Online since" line in the heartbeat
    message. Compute the span from a wall-clock epoch instead of millis(),
    so it stays correct past the ~49-day millis() wrap.
    Convert the /status "Uptime" field the same way, deriving it from a
    boot epoch captured once at NTP sync. Extract formatDuration() and
    formatDurationSince() helpers; drop formatUptime().
    Claude-Session: https://claude.ai/code/session_015sXuJnyEgMYEZCrQqkwXPp
    [main.cpp]
2026-07-24 Drop misleading relative 'ago' from Online since line
    The heartbeat message is edited in place, but the '(Xd Yh Zm ago)'
    suffix was computed only at edit time. Between heartbeats it drifted by
    up to the heartbeat interval, and after the device died it froze forever
    at a stale value. Keep only the absolute 'Online since' timestamp, which
    stays correct indefinitely; 'Last seen' already conveys liveness.
    Claude-Session: https://claude.ai/code/session_01Jgaq686KkB4SBe9Hq2YUaa
    [main.cpp]
2026-07-24 Show heartbeat interval in messages and /status
    Append the configured HEARTBEAT_MIN to the heartbeat message's 'Last
    seen' line and add a 'Heartbeat: every Nm' line to /status, so the
    reader knows the refresh cadence and can judge when a frozen 'Last seen'
    means the device is gone.
    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
2026-07-24 Persist message in NVS; ping only on real power-on; mute toggle
    Keep {message_id, online_since, muted} in NVS and classify each boot with
    esp_reset_reason(). A genuine power-on (ESP_RST_POWERON) while unmuted is
    the only event that sends a notifying message; a soft reboot (watchdog /
    OTA) or a muted restart silently resumes the same message in place,
    keeping the persistent online_since. Uptime is tracked from this boot and
    shown separately in /status.
    Add /mute and /unmute chat commands (persistent toggle, muted by default,
    so the first power-on and the reboot-heavy setup phase are silent). /mute
    acks before power-down; /unmute arms pings. /status shows Mute: on/off.
    Supersedes ADR-0003 (n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
    [main.cpp]
2026-07-24 docs: reconcile CONCEPT with NVS model; add ADR-0009/0010
    Update CONCEPT.md to the implemented model (ADR-0008): message state
    lives in NVS, the boot is classified by esp_reset_reason(), a
    notification fires only on a genuine un-muted power-on, /mute-/unmute
    toggle it (muted by default), and soft reboots resume the same message
    silently. Rewrites the 'no NVS' lifecycle text and the §7.2
    false-positive note, refreshes the status line and the related-ADR list.
    Record two verified facts as ADRs and cross-link them from 0004/0008:
    - ADR-0009: editMessageText is limited to 48h in chats/groups but is
    unlimited in channels; a private chat rotates a silent message ~every
    2 days, a channel does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
2026-07-24 Replace always-on "Online since" in message with armed-only "On since"
    The heartbeat message no longer shows a persistent "Online since" line:
    that value is preserved across muted/planned restarts, so it overstated
    continuity (and while muted it froze at the first-boot time).
    Instead, show an "On since" line only when un-muted. A new message is
    created only on a genuine armed power-on, so g_onlineSince is the real
    turn-on time there; the line is hidden while muted, where the message is
    reused and that time would be stale. /status still reports the value as
    "Online since" alongside Uptime.
    Claude-Session: https://claude.ai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
    [main.cpp]
2026-07-24 Treat "message is not modified" edit response as success
    editMessageText returns HTTP 400 "message is not modified" when the new
    text equals the current message content (e.g. a reboot within the same
    minute as the last heartbeat produces an identical Last seen line). The
    code treated any non-200 as a failed edit and fell back to posting a
    fresh message, spuriously duplicating the tracked message. Treat that
    specific response as success so no new message is sent.
    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
    [main.cpp]
2026-07-24 Drop "Im alive —" prefix; omit device line when DEVICE_NAME is empty
    The heartbeat message no longer starts with "Im alive — ". When
    DEVICE_NAME is set it is shown alone as the first line; when empty, no
    device line is emitted and the message starts at "On since"/"Last seen".
    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
    [main.cpp]
2026-07-24 Restrict commands to TG_ADMIN_IDS; show config in /status
    Add a TG_ADMIN_IDS allowlist: pollCommands now checks message.from.id
    and ignores commands from anyone not on the list (the update offset still
    advances). An empty list allows no one (fail-safe).
    /status now reports Name, WiFi SSID, Chat (TG_CHAT_ID), TZ, and the admin
    IDs alongside the existing runtime state; the WiFi password and bot token
    are never shown. See ADR-0011.
    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
    [main.cpp]
2026-07-24 Render the time in bold in the heartbeat message
    Send the heartbeat message with parse_mode=HTML and wrap the leading
    HH:MM of each timestamp in <b></b>, so Telegram shows the time in bold
    and the date in regular weight. /status replies and command acks stay
    plain text. DEVICE_NAME must now avoid < > & (noted in config.example.h).
    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
    [main.cpp]
2026-07-24 Revert "Render the time in bold in the heartbeat message"
    This reverts commit dc870ee2ad03c3d2e0d8f905328dca0dba808698.
    [main.cpp]
2026-07-24 Phase-lock heartbeat edits to round wall-clock times
    Add a HEARTBEAT_ALIGN compile-time flag (default on) that snaps each
    heartbeat edit to the next local minute that is a multiple of
    HEARTBEAT_MIN, so "Last seen" values land on a tidy grid (e.g. :00, :05,
    :10). It applies only when the interval divides an hour evenly
    (60 % HEARTBEAT_MIN == 0); other intervals keep the relative-millis()
    timer unchanged. The target is recomputed from wall-clock each cycle so
    it tracks NTP re-syncs. A 30 s guard skips a boundary landing right
    after a power-on, so two edits never fire seconds apart (well under
    Telegram's ~1 request/second per-chat limit). Notification, mute,
    edit-fallback and NVS logic are unto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
    [main.cpp]
2026-07-25 Add OTA updates over Telegram and admin boot notices
    An admin sends the built firmware.bin as a document captioned /update;
    the device streams it into the spare OTA slot, reboots, and must confirm
    itself within three boots or it rolls back to the previous image
    (ADR-0013). Every boot now also sends a silent notice (reset reason and
    firmware version) to each admin's private chat, making soft reboots
    visible without touching the main chat.
    Claude-Session: https://claude.ai/code/session_015rA58UzTNC3XeLH9h6MC1z
    [main.cpp]
2026-07-25 Fix loopTask stack overflow in the OTA download path
    otaDownloadAndFlash and handleOtaDocument are static with a single
    caller, so GCC inlines them into pollCommands; the 4 KB download buffer
    then sat in pollCommands' stack frame (~5.2 KB total), overflowing the
    8 KB loopTask stack on every command poll as soon as the TLS machinery
    was entered - the device crash-looped with "stack overflow in task
    loopTask" every ~30 s. Move the buffer to static storage; the frame is
    back to ~1 KB. Verified 115 s of stable operation over serial after a
    hard reset.
    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
    [main.cpp]
2026-07-25 Add device and board images to README
    Claude-Session: https://claude.ai/code/session_01XwAtfP3FZQBB4soZtGUvUW
2026-07-25 Add 3D-printable case and refresh board image
    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
    [bottom.stl, top.stl]
2026-07-30 Bound the TLS handshake so it cannot outlast the task watchdog
    An admin boot notice reported a task-watchdog reboot. The Arduino core
    defaults WiFiClientSecure's handshake timeout to 120 s - twice
    WDT_TIMEOUT_S - so a stalled TLS handshake (link up, packets not getting
    through) reboots the device instead of failing the request.
    - Cap the handshake at TLS_HANDSHAKE_S (10 s) in both HTTPS paths.
    - Feed the watchdog after each completed Telegram request. Every path is
    now time-bounded, so a burst of consecutive requests - a heartbeat edit
    falling back to a fresh send, or the several sends in setup() - can no
    longer add up past the timeout.
    - Record boot diagnostics in NVS (previous boot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
    [main.cpp]
2026-07-30 Accept any .bin document as firmware, dropping the /update caption
    Adding a caption is manual work on every update and the step most easily
    forgotten on mobile; a document sent without it was silently ignored,
    which reads as a device failure rather than a missing caption. The device
    has a single operator, who is on the admin allowlist (ADR-0011), so the
    accident the gate guarded against is not a realistic event.
    Match on the document name instead: any admin document whose name ends in
    .bin (case-insensitive) is flashed, and captions are ignored, so a
    document still captioned /update keeps working. ADR-0016 records the
    amendment to ADR-0013 section 1; the boot-count rollback remains the
    safe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
    [main.cpp]
2026-07-31 Drop the vestigial /update command
    Since any .bin document from an admin is treated as firmware, /update no
    longer triggers anything. Remove it from the setMyCommands menu and the
    command handler, and document the OTA flow in its own README section
    instead of as a command. Recorded as ADR-0017.
    Claude-Session: https://claude.ai/code/session_01RSrr4jcabCDeZD7PJqPmkJ
2026-08-02 Post a fresh message only when Telegram rejects the edit
    tgEditMessage collapsed every failure into one false, so a stalled TLS
    handshake, a read timeout, a 5xx or a flood wait were indistinguishable
    from Telegram refusing to edit the message. Each of them cost a new
    message: a hiccup on 2 Aug rotated a channel post that had been edited
    in place for nine days, with no reboot behind it.
    Classify the outcome instead. HTTP 400 means the message is deleted or
    past its edit window, so the fallback still posts a fresh silent one;
    anything else is transient and is retried three times before the update
    is left to the next heartbeat. The resume path in setup() follows the
    same rule, so a boot on a f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
    [main.cpp]
